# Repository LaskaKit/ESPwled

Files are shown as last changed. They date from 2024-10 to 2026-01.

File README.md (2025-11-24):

# LaskaKit ESPwled

Are you looking for a board that is compatible with the WLED project, which makes it easy to control a variety of LED strips without programming? Then look no further.
Simply upload the WLED program into Laskakit ESPwled from [web browser](https://kno.wled.ge/).

First you connect the board via USB-C cable and then the ESP32-C3, on which the board is based, into recording mode. You do this by pressing and holding the FLASH button, pressing and releasing the RESET button, and then releasing the FLASH button as well. 
You then select the connected Laskakit ESPwled board in the browser and load the program. You will connect to the AP (Wi-Fi access point) that ESPwled created, via, for example, your phone, and fill in your Wi-Fi name and password. Then ESPwled already connects to your wifi and you control the connected LED strips via your browser on your phone, computer or tablet.

The GPIO data pin that is used to control the LED strips is 5, not pin 2 as it is in the default WLED settings -> so it is in the WLED settings to change this pin via the web browser. 
If the LED strip also has a CLK signal, this is connected to GPIO 4.

MicroESPink is equipped with our[universal I2C uŠup port connector](https://blog.laskakit.cz/predstavujeme-univerzalni-konektor-pro-propojeni-modulu-a-cidel-%CE%BCsup/) to which you can connect various sensors - [SHT40 (temperature, humidity)](https://www.laskakit.cz/laskakit-sht40-senzor-teploty-a-vlhkosti-vzduchu/), [BME280 (pressure, temperature, humidity)](https://www.laskakit.cz/arduino-senzor-tlaku--teploty-a-vlhkosti-bme280/), [SCD41 (CO2, temperature, humidity)](https://www.laskakit.cz/laskakit-scd41-senzor-co2--teploty-a-vlhkosti-vzduchu/), [BH1750 (lighting)](https://www.laskakit.cz/laskakit-bh1750-snimac-intenzity-osvetleni/), [APDS-9960 (gesture sensor)](https://www.laskakit.cz/laskakit-apds-9960-senzor-priblizeni-a-gest/) and many other sensors. </br>
Our I2C ushup connector is compatible with Adafruit Stemma and Qwiik from Sparkfun.</br>

The I2C bus is connected as follows, SDA GPIO10, SCL GPIO8. Before initializing the I2C module, it is necessary to add a definition of which pins are on which: wire.begin(10, 8); // (SDA,SCL)

In addition to the I2C uŠup connector, the board has an SPI uŠup connector to which you can connect other SPI peripherals. 

ESPwled has an addressable LED connected to GPIO 9. To control this LED we have a predefined [our example code on ESPwled github](https://github.com/LaskaKit/ESPwled/tree/main/SW).

You may need additional ones: The board comes without LED connector, the pitch is 2.54mm. You can buy [1pc 4pin JST-XH rigth angle](https://www.laskakit.cz/jst-xh-2-54mm-konektor-do-dps--pravouhly/?variantId=5393) or [2pc 2 pin screw terminal block for KF128-2.54 PCB](https://www.laskakit.cz/sroubovaci-svorkovnice-do-dps-kf128-2-54/?variantId=8871) or pin rail. Suitable pigtail with IPEX3 connector for IPEX versions - [Pigtail MHF3/IPEX3 - SMA Female](https://www.laskakit.cz/pigtail-mhf3-ipex3-sma-female--kabel-1-15mm--15cm/), 1.15mm cable, 15cm

Default WLED firmware does not support microphone input for ESP32-C3 (ESPwled), if the microphone input is needed it is necessary to compile WLED firmware with different setting. 

ESPwled connection you may check on the picture below
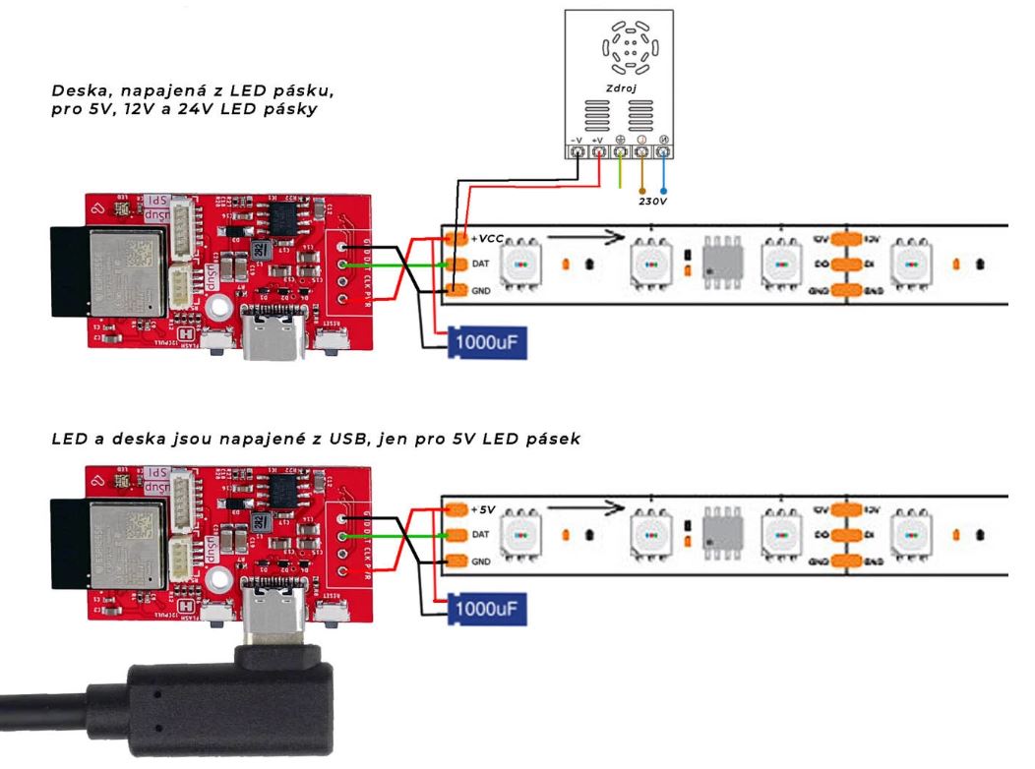
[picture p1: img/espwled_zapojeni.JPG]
ESPwled zapojení LED pásku


The 5V LED strip can thus be powered from the USB-C that is on the board. The 5V, 12 and up to 24V strips then need an external power supply from which the ESPwled can also be powered. 

## ESPwled board is available on https://www.laskakit.cz/laskakit-espwled/?variantId=16928

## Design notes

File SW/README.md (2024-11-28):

### LaskaKit ESPwled is optimalised for WLED software: https://kno.wled.ge
Installation: https://kno.wled.ge/basics/install-binary/
#### Install using web browser: simply installation, just press install https://install.wled.me/ 

#### Install using Platformio https://kno.wled.ge/advanced/compiling-wled/
* Uncomment  default_envs = esp32c3dev in platformio.ini

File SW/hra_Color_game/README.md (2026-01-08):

# ESPWLED Color Game

Webová arkádová hra pro **ESPWLED s ESP32-C3** a **WS2812B LED pásek**, ovládaná přes webový prohlížeč.
Herní logika běží přímo na ESP32-C3, bez cloudu a bez externích služeb.

LED pásek slouží jako herní pole, po kterém se pohybují barevné střely hráče a nepřítele.
Hráč reaguje výběrem správné barvy pomocí webového rozhraní.

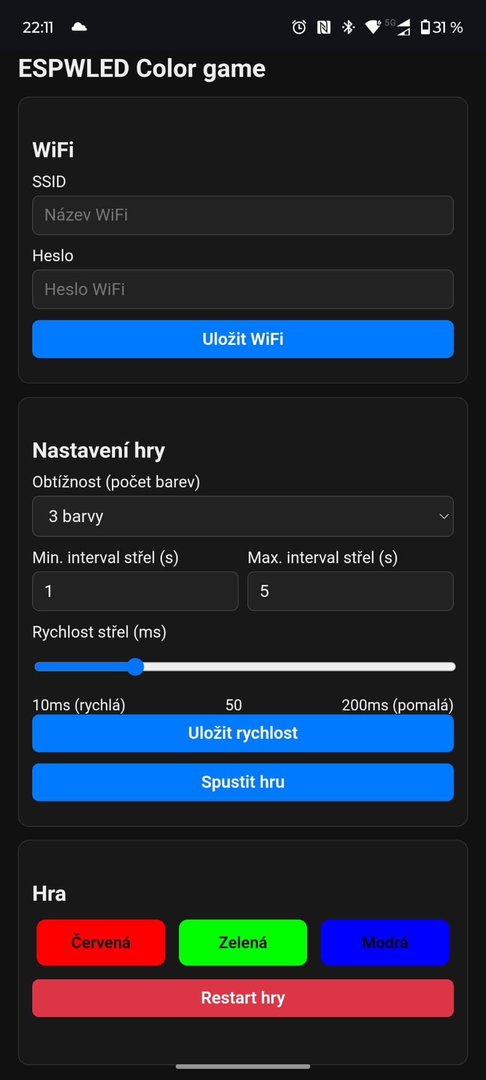
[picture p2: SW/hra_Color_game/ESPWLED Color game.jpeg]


---

## Hlavní vlastnosti

- Arkádová hra běžící přímo na ESPWLED
- Ovládání přes webové rozhraní (PC / mobil)
- LED pásek WS2812B jako herní plocha
- Wi-Fi Access Point + volitelný STA režim
- Ukládání nastavení do NVM (Preferences)
- Nastavitelná obtížnost (počet barev)
- Nastavitelný interval nepřátelské střelby
- Nastavitelná rychlost pohybu střel (10–200 ms)
- Barevné kolize a vizuální exploze
- Offline provoz, žádný cloud

---

## Použitý hardware

- ESPWLED s ESP32-C3 (https://www.laskakit.cz/laskakit-espwled/?variantId=16928)
- WS2812B LED pásek (například https://www.laskakit.cz/led-pasek-neopixel-ws2812b-60led-m-ip30-5m-bily/
- Počet LED: 120 (pro pásek 60 LED/m je potřebná délka 2m)
- Datový pin LED: GPIO 5 (označený na desce jako DAT)

---

## Zapojení LED pásku

| WS2812B | ESPWLED |
|---|---|
| DIN | GPIO 5 (DAT) |
| +5V | 5V (PWR) |
| GND | GND |

Doporučení:
- použijte samostatný 5V zdroj pro LED pásek nebo jej napájejte ESPWLED z USB-C
- nezapomeňte na společnou zem (GND)

---

## Wi-Fi režimy

### Access Point (AP)

ESP32 vždy spustí vlastní Wi-Fi síť:

- SSID: `ESPWLED-Color game`
- Heslo: `espwledgame`
- IP adresa: `192.168.4.1` (typicky)

### Station (STA)

- Připojení k existující Wi-Fi
- Nastavuje se přes webové rozhraní
- Údaje se ukládají do NVM
- Po restartu se ESP automaticky připojí

- SSID a IP adresou jsou zobrazeny v Serial Monitor

---

## Webové rozhraní

Po připojení k ESP otevřete IP adresu v prohlížeči.

### Funkce webu

#### Wi-Fi
- Zadání SSID a hesla
- Uložení do NVM

#### Nastavení hry
- Obtížnost (3 / 4 / 6 / 8 barev)
- Minimální interval střel nepřítele (s)
- Maximální interval střel nepřítele (s)
- Rychlost pohybu střel (10–200 ms)

#### Ovládání hry
- Spuštění hry
- Barevná tlačítka pro střelbu
- Restart hry

---

## Herní princip

- Hráčova základna je na začátku LED pásku
- Nepřítel je na konci LED pásku
- Obě strany vystřelují barevné střely
- Střely se pohybují po LED pásku
- Pokud se střely stejné barvy setkají → exploze
- Pokud nepřátelská střela dosáhne hráčovy základny → konec hry
- Skóre se zvyšuje za každý úspěšný zásah

---

## Ukládaná nastavení (Preferences)

Do NVM se ukládá:

- STA Wi-Fi SSID
- STA Wi-Fi heslo
- Rychlost pohybu střel (shotSpeedMs)

Po restartu zařízení se tato nastavení automaticky načtou.

---

## Použité knihovny

- WiFi
- Preferences
- Adafruit NeoPixel
- ESPAsyncWebServer
- AsyncTCP

---

## Poznámky k výkonu

- Pohyb střel je řízen pomocí `millis()`
- Rychlost střel je globální pro hráče i nepřítele
- LED rendering probíhá v každé iteraci `loop()`
- Exploze jsou časově řízené s plynulým zhasínáním

---

## Licence

Creative Commons BY-NC 4.0

---

Laskakit (2026)

ESPWLED - https://www.laskakit.cz/laskakit-espwled/?variantId=16928

LED pásek - https://www.laskakit.cz/led-pasek-neopixel-ws2812b-60led-m-ip30-5m-bily

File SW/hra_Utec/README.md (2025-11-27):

# Uteč! – ESPWLED hra s adresovatelným LED páskem





**Uteč!** je interaktivní hra pro [ESPWLED (ESP32-C3)](https://www.laskakit.cz/laskakit-espwled/?variantId=16925), kde hráč závodí s duchem po LED polích. Cílem je dosáhnout koncového pole dříve než duch. Hráč postupuje odpovídáním na otázky, duch postupuje při chybné odpovědi.

---
 
  ## Hardware

| Komponenta | Specifikace | Odkaz |
|---|---|---|
| ESPWLED | ESP32-C3 + LED driver | [laskakit.cz](https://www.laskakit.cz/laskakit-espwled/?variantId=16925) |
| LED pásek | WS2812B, 120 LED (2m/60LED/m) | [laskakit.cz WS2812B](https://www.laskakit.cz/vyhledavani/?string=ws2812b) [LaskaKit ESPwled adaptér pro LED pásek JST-SM-3](https://www.laskakit.cz/laskakit-espwled-adapter-pro-led-pasek-jst-sm-3--10-cm/), [4pinový konektor pro LED pásek](https://www.laskakit.cz/jst-xh-2-54mm-konektor-do-dps--pravouhly/?variantId=5393) |
| Napájení | 5V/2A+ | [USB adapter](https://www.laskakit.cz/sitovy-napajeci-adapter-5v-3a--kabel-usb-c-usb-a-vypinac) | 

- Počet LED: 120 (8 LED na pole), pásek ve verzi 60LED/m zkraťte na 2m
- LED pásek i ESPWLED se bude napájet z nabíječky s USB-C konektorem. Nabíjecí adaptér musí být minimálně 5V/3A

**Propojení:**  
`LED_DATA → DAT(GPIO5)`  
`LED_GND → GND`  
`LED_5V → PWR(5V)`

---

## Software & Knihovny

- **Arduino framework pro ESP32-C3**
- **Knihovny:**
  - [Adafruit_NeoPixel](https://github.com/adafruit/Adafruit_NeoPixel) – ovládání LED pásu
  - [AsyncTCP](https://github.com/me-no-dev/AsyncTCP) – asynchronní TCP
  - [ESPAsyncWebServer](https://github.com/me-no-dev/ESPAsyncWebServer) – web server
  - Preferences – ukládání Wi-Fi přihlašovacích údajů

---

## Princip hry

1. Hráč začíná na poli 3, duch na poli 1.
2. Správná odpověď → hráč postupuje o 1 pole.
3. Špatná odpověď → duch postupuje o 1–3 pole podle kola.
4. Možnost **"Ještě jednou"** max 2x, pro přeskočení otázky bez pohybu ducha.
5. LED pás zobrazuje:
   - Zelené LED = hráč
   - Červené LED = duch
   - Ostatní pole = dimované LED
6. Konec hry:
   - Hráč dosáhne posledního pole → výhra hráče
   - Duch dohoní hráče → výhra ducha

---

## Formát otázek

Otázky se nahrávají přes webové rozhraní v tomto formátu (7 polí, oddělených středníkem):
	`ID;Otázka;Odpověď1;Odpověď2;Odpověď3;Odpověď4;IndexSprávnéOdpovědi(1..4)`

### Prompt pro generování otázek a odpovědí
Jsi AI generátor kvízových otázek. Vytvoř prosím otázky ve formátu vhodném pro hru **"Uteč!"** na ESP32-C3.</br>
Otázky musí být zaměřeny na (**zde zadejte téma otázek**). </br>
*Např. Matematiku Základní školy pro první stupeň, Fyziku pro střední školu, Všeobecné znalosti o Evropské Unii a jiné*</br>
Každá otázka musí mít přesně 7 částí oddělených středníkem (`;`):</br>

ID otázky;Otázka;Odpověď1;Odpověď2;Odpověď3;Odpověď4;Index Správné odpovědi (od 1 do 4)

Pravidla

1. **ID** musí být číslo větší než 0, unikátní pro každou otázku.  
2. **Otázka** musí být jasná, krátká a srozumitelná.  
3. Každá otázka musí mít **4 možné odpovědi**.  
4. **Správná odpověď** je číslo od 1 do 4 podle pořadí odpovědí.  
5. **Nepoužívej čárky** mezi odpověďmi, protože pole se oddělují středníkem.  
6. Vytvoř **30 otázek** v tomto formátu.  
7. Výstup má být **čistě textový**, každá otázka na novém řádku, bez úvodních komentářů.

Příklad</br>
1;Kolik je 2+2?;3;4;5;6;2</br>
2;Hlavní město Francie?;Paříž;Londýn;Berlín;Řím;1

---

## Instalace

1. Nainstalujte Arduino IDE s podporou ESP32-C3.
2. Nainstalujte knihovny:
   - Adafruit_NeoPixel
   - AsyncTCP
   - ESPAsyncWebServer
3. Povolte USB CDC On Boot (menu - Tools - nastavit na Enabled)
4. Nahrajte `hra_Utec.ino` do ESPWLED.
   - Pokud nelze program do ESPWLED nahrát, přepněte jej manuálně do bootloader módu.
   - Připojte nabíjecí adaptér do USB-C konektoru.
   - Stiskněte a držte tlačítko FLASH
   - Stiskněte a uvolněte tlačítko RESET
   - Uvolněte tlačítko RESET
   - Nahrajte program do ESPWLED
5. Po spuštění:
   - ESPWLED (ESP32-C3) vytvoří Wi-Fi Access Point `hraUtecAP` (heslo `utec1234`).
   - Připojte se přes prohlížeč na `http://192.168.4.1`.
   - Nahrajte otázky a spusťte hru.

> Pokud uložíte Wi-Fi přihlašovací údaje, ESP32-C3 (ESPWLED) se automaticky pokusí připojit k domácí síti a AP zůstane aktivní jako fallback.

---

## Webové rozhraní

- Zobrazení aktuální otázky a odpovědí
- Odeslání odpovědi
- Přeskočení otázky (`Ještě jednou`)
- Restart hry
- Nahrání nových otázek
- Nastavení Wi-Fi

LED pás zobrazuje dynamicky pozice hráče a ducha.

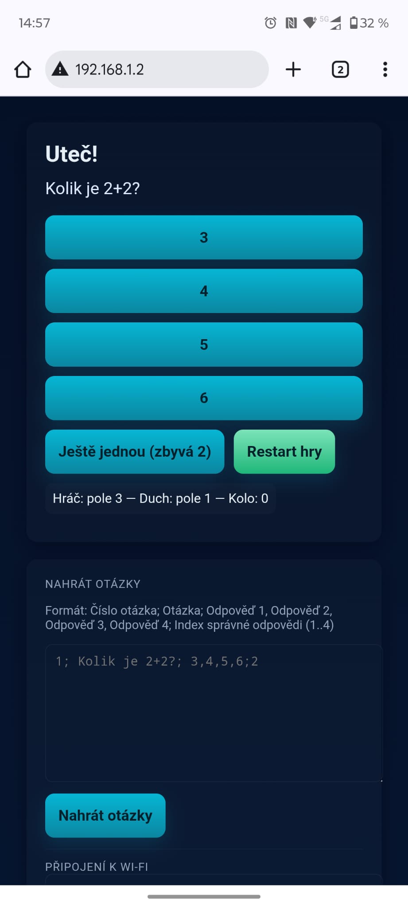
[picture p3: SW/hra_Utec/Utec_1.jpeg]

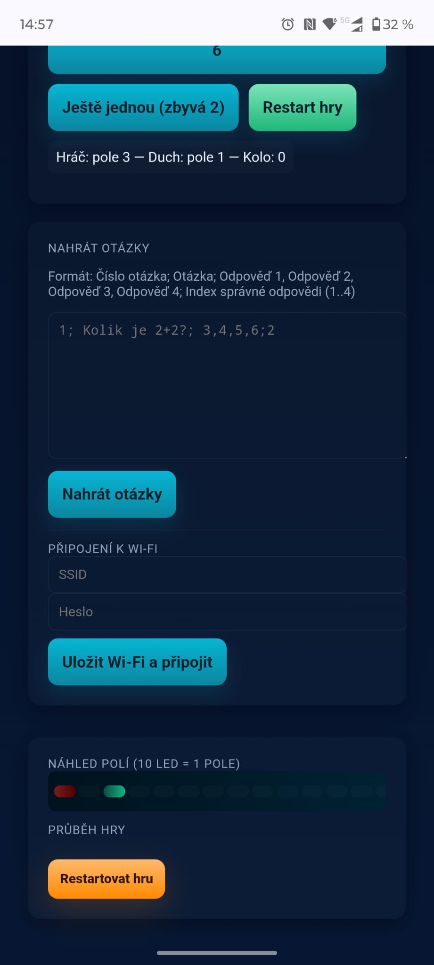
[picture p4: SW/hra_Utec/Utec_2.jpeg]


---

## Ukázka LED zobrazení

- Zelené = hráč  
- Červené = duch  
- Modré (dimované) = pole

---

### ESPWLED, LED pásek i USB adaptér koupíte na [laskakit.cz](https://www.laskakit.cz/laskakit-espwled/?variantId=16925)
---

## Licence

Projekt je open-source a můžete jej používat a upravovat podle potřeby. 

laskakit.cz 2025

---

*Vytvořeno pro zábavu a vzdělávací účely – hra kombinuje ESPWLED, NeoPixel a webové rozhraní.*

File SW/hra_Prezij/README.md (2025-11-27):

# hra Přežij! ESPWLED hra s adresovatelným LED páskem





## Popis projektu

**Interaktivní kvízová hra "Přežij!"** pro ESP32-C3 (ESPWLED), kde hráč odpovídá na otázky a snaží se zničit nepřítele střelami vystřelenými díky správným odpovědím. Nepřítel střílí zpět každé **4 sekundy** a hráč musí být rychlejší!

### Jak hrát

- **Správná odpověď**: vystřelí protistřelu (z LED 0 → LED 119) 🟢  
- **Špatná odpověď**: žádná střela ❌  
- **Kolize střel**: exploze, zbylé střely pokračují 💥  
- **Výhra**: hráčova střela dosáhne nepřítele (LED 119) 🎉  
- **Prohra**: nepřátelova střela dosáhne hráče (LED 0) 💀  

## Požadavky

### Hardware

| Komponenta | Specifikace | Odkaz |
|---|---|---|
| ESPWLED | ESP32-C3 + LED driver | [laskakit.cz](https://www.laskakit.cz/laskakit-espwled/?variantId=16925) |
| LED pásek | WS2812B, 120 LED (2m/60LED/m) | [laskakit.cz WS2812B](https://www.laskakit.cz/vyhledavani/?string=ws2812b) |
| Napájení | 5V/2A+ | [USB adapter](https://www.laskakit.cz/sitovy-napajeci-adapter-5v-3a--kabel-usb-c-usb-a-vypinac) | 

LED pásek i ESPWLED se bude napájet z nabíječky s USB-C konektorem. Nabíjecí adaptér musí být minimálně 5V/3A
LED pásek ve verzi 60LED/m zkraťte na 2m

**Propojení:**  
`LED_DATA → DAT(GPIO5)`  
`LED_GND → GND`  
`LED_5V → PWR(5V)`

## Vlastnosti

- Webové UI přes WiFi AP (SSID: hraPrezijAP, heslo: prezij1234)  
- Otázky se nahrávají přes webové rozhraní v tomto formátu (7 polí, oddělených středníkem):
	`ID;Otázka;Odpověď1;Odpověď2;Odpověď3;Odpověď4;IndexSprávnéOdpovědi(1..4)`
- Uložení WiFi přihlašovacích údajů (automatické připojení)  
- 2x "Ještě jednou" (skip otázky)  
- Real-time animace střel a exploze (50ms krok)  
- Otázky uložené v RAM (max 200 otázek)

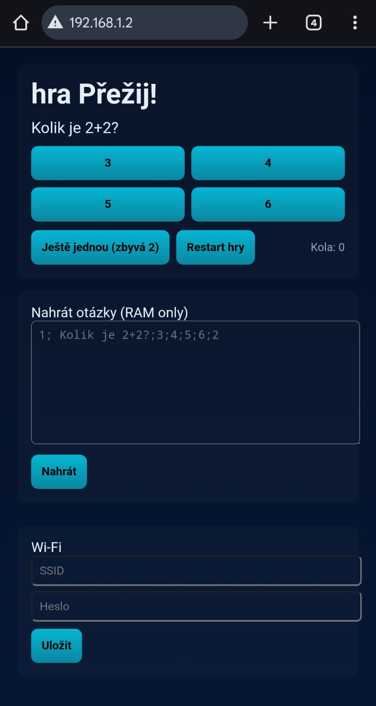
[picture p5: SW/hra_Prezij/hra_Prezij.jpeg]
Webová stránka hry
  

### Prompt pro generování otázek a odpovědí
Jsi AI generátor kvízových otázek. Vytvoř prosím otázky ve formátu vhodném pro hru **"Uteč!"** na ESP32-C3.</br>
Otázky musí být zaměřeny na (**zde zadejte téma otázek**). </br>
*Např. Matematiku Základní školy pro první stupeň, Fyziku pro střední školu, Všeobecné znalosti o Evropské Unii a jiné*</br>
Každá otázka musí mít přesně 7 částí oddělených středníkem (`;`):</br>

ID otázky;Otázka;Odpověď1;Odpověď2;Odpověď3;Odpověď4;Index Správné odpovědi (od 1 do 4)

Pravidla

1. **ID** musí být číslo větší než 0, unikátní pro každou otázku.  
2. **Otázka** musí být jasná, krátká a srozumitelná.  
3. Každá otázka musí mít **4 možné odpovědi**.  
4. **Správná odpověď** je číslo od 1 do 4 podle pořadí odpovědí.  
5. **Nepoužívej čárky** mezi odpověďmi, protože pole se oddělují středníkem.  
6. Vytvoř **30 otázek** v tomto formátu.  
7. Výstup má být **čistě textový**, každá otázka na novém řádku, bez úvodních komentářů.

Příklad</br>
1;Kolik je 2+2?;3;4;5;6;2</br>
2;Hlavní město Francie?;Paříž;Londýn;Berlín;Řím;1

## Instalace

1. Nainstalujte Arduino IDE s podporou ESP32-C3.
2. Nainstalujte knihovny:
   - Adafruit_NeoPixel
   - AsyncTCP
   - ESPAsyncWebServer
3. Povolte USB CDC On Boot (menu - Tools - nastavit na Enabled)
4. Nahrajte `hra_Prezij.ino` do ESPWLED.
   - Pokud nelze program do ESPWLED nahrát, přepněte jej manuálně do bootloader módu.
   - Připojte nabíjecí adaptér do USB-C konektoru.
   - Stiskněte a držte tlačítko FLASH
   - Stiskněte a uvolněte tlačítko RESET
   - Uvolněte tlačítko RESET
   - Nahrajte program do ESPWLED
5. Po spuštění:
   - ESPWLED (ESP32-C3) vytvoří Wi-Fi Access Point `hraPrezijAP` (heslo `prezij1234`).
   - Připojte se přes prohlížeč na `http://192.168.4.1`.
   - Nahrajte otázky a spusťte hru.

> Pokud uložíte Wi-Fi přihlašovací údaje, ESP32-C3 (ESPWLED) se automaticky pokusí připojit k domácí síti a AP zůstane aktivní jako fallback. Není pak nutné se připojovat telefonem k WiFI hraPrezijAP, ale zůstat v domácí síti

## Ukázka LED zobrazení

- Zelené = střela hráče  
- Červené = střela protivníka  
- Modré (dimované) = pole

---

### ESPWLED, LED pásek i USB adaptér koupíte na [laskakit.cz](https://www.laskakit.cz/laskakit-espwled/?variantId=16925)
---

## Licence

Projekt je open-source a můžete jej používat a upravovat podle potřeby. 

laskakit.cz 2025

---

*Vytvořeno pro zábavu a vzdělávací účely – hra kombinuje ESPWLED, NeoPixel a webové rozhraní.*

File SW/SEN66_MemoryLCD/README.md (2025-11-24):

# SEN66 + ESPwled (ESP32-C3) + MemoryLCD + RGB LED

**Autor:** [laskakit.cz](https://www.laskakit.cz) (2025)

## Popis
Projekt pro čtení hodnot ze senzoru **Sensirion SEN66** (CO₂, teplota, vlhkost, VOC, NOx, PM2.5)  
a jejich zobrazení na **Sharp Memory LCD** (400x240).  

Hodnoty se vykreslují dynamicky – před každým překreslením se smaže oblast podle **bounding boxu** staré i nové hodnoty,  
aby nezůstávaly zbytky při změně délky čísla (např. `99 → 100`).  

**RGB LED** signalizuje kvalitu vzduchu podle koncentrace CO₂.

---

## Nutné knihovny
- [Adafruit_GFX](https://github.com/adafruit/Adafruit-GFX-Library)  
- [Adafruit_SharpMem](https://github.com/adafruit/Adafruit_SHARP_Memory_Display)  
- [Adafruit_NeoPixel](https://github.com/adafruit/Adafruit_NeoPixel)  
- [SensirionI2cSen66](https://github.com/Sensirion/arduino-i2c-sen66)  

---

## Hardware
- [ESPwled (ESP32-C3)](https://www.laskakit.cz/laskakit-espwled/)  
- [SEN66 (I2C)](https://www.laskakit.cz/senserion-sen66-sin-t-senzor-kvality-ovzdusi/)  
- [Propojovací kabel I2C uŠup](https://www.laskakit.cz/laskakit-airboard-propojovaci-kabel-pro-senserion-sen6x-senzor-kvality-ovzdusi/)  
- [Sharp Memory LCD 400x240 (SPI)](https://www.laskakit.cz/laskakit-2-7--400x240-lcd-memory-displej/)  
- [Propojovací kabel SPI uŠup](https://www.laskakit.cz/--sup-spi-jst-sh-6-pin-kabel-10cm/)  

---

## Ukázka výstupu
- Na LCD se zobrazuje:  
  - CO₂ (ppm)  
  - Teplota (°C)  
  - Relativní vlhkost (%)  
  - VOC index  
  - NOx index  
  - PM2.5 (µg/m³)  

- RGB LED svítí:  
  - 🟢 zeleně při CO₂ < 800 ppm  
  - 🟡 žlutě při 800–1400 ppm  
  - 🔴 červeně při CO₂ > 1400 ppm  
  - 🔵 modře při chybě senzoru

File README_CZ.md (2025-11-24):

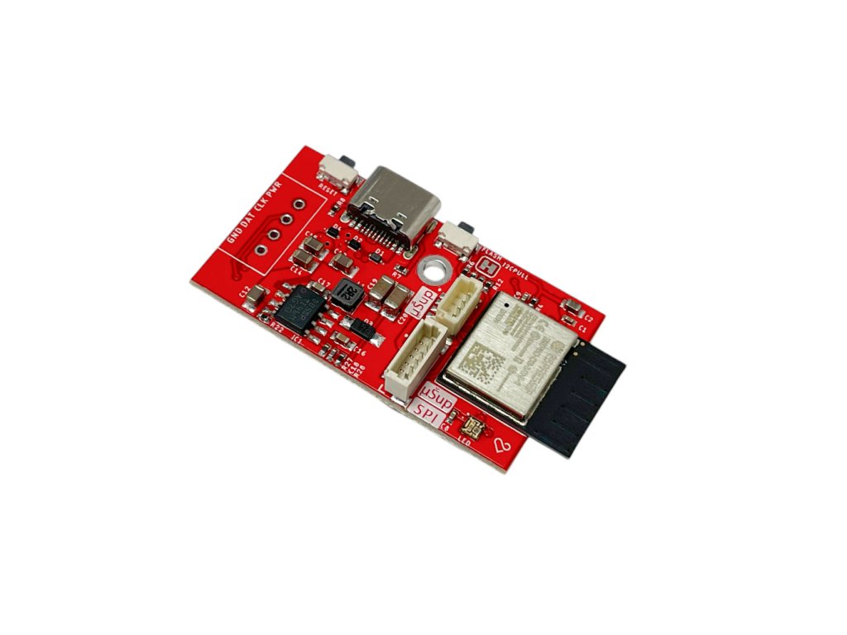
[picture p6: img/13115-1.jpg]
ESPwled

# LaskaKit ESPwled

Hledáš desku, která je kompatibilní s projektem WLED, který přináší naprosto jednoduché ovládání nejrůznějších LED pásků bez nutnosti programování? Pak už dál hledat nemusíš.
Program WLED do Laskakit ESPwled nahraješ jednoduše z [webového prohlížeče projektu](https://kno.wled.ge/).

Nejprve připojíš desku skrze USB-C kabel a pak ESP32-C3, na kterém je deska založena, do nahrávacího režimu. To provedeš tak, že zmáčkneš a držíš tlačítko FLASH, zmáčkneš a uvolníš tlačítko RESET a poté uvolníš i tlačítko FLASH. 
Poté v prohlížeči vybereš připojenou Laskakit ESPwled desku a nahraješ program. Připojíš se na AP (Wi-Fi access point), kterou ESPwled vytvořil, přes třeba tvůj telefon a vyplníš jméno a heslo tvé Wi-Fi. Poté se ESPwled už připojí do tvé wifi a přes tvůj prohlížeč v telefonu, počítači nebo tabletu ovládáš připojené LED pásky.

DAtový GPIO pin, který se používá na ovládání LED pásků je 5, ne pin 2 jak je ve výchozím nastavení WLED -> je tedy v nastavení WLED tento pin změnit skrze webový prohlížeč. 
Pokud má LED pásek i CLK signál, ten je připojen na GPIO 4.

Deska samotná obsahuje navíc [náš univerzální I2C uŠup konektor](https://blog.laskakit.cz/predstavujeme-univerzalni-konektor-pro-propojeni-modulu-a-cidel-%CE%BCsup/) ke kterým můžeš připojit nejrůznější čidla - [SHT40 (teplota, vlhkost)](https://www.laskakit.cz/laskakit-sht40-senzor-teploty-a-vlhkosti-vzduchu/), [BME280 (tlak, teplota, vlhkost)](https://www.laskakit.cz/arduino-senzor-tlaku--teploty-a-vlhkosti-bme280/), [SCD41 (CO2, teplota, vlhkost)](https://www.laskakit.cz/laskakit-scd41-senzor-co2--teploty-a-vlhkosti-vzduchu/), [BH1750 (osvětlení)](https://www.laskakit.cz/laskakit-bh1750-snimac-intenzity-osvetleni/), [APDS-9960 (senzor gest)](https://www.laskakit.cz/laskakit-apds-9960-senzor-priblizeni-a-gest/) a spoustu další senzorů. </br>
Náš I2C uŠup konektor je kompatibilní s Adafruit Stemma a Qwiik od Sparkfun.</br>
I2C sběrnice je připojeno takto, SDA GPIO10, SCL GPIO8. Je potřeba před iniciací i2c modulu přidat definici na kterých PINech jsou: Wire.begin(10, 8); // (SDA,SCL)

Kromě I2C uŠup konektoru má deska i SPI uŠup konektor, ke kterému můžeš připojit další SPI periférie. 

ESPwled má osazenou adresovatelnou LED připojenou na GPIO 9. Pro ovládání této LED máme předpřiravený [vlastní vzorový kód na našem github](https://github.com/LaskaKit/ESPwled/tree/main/SW).

Dodatečné možna budeš potřebovat:
Deska je dodávána bez LED konektoru, rozteč je 2.54mm. Můžeš dokoupit 1ks [4pin JST-XH pravoúhlý](https://www.laskakit.cz/jst-xh-2-54mm-konektor-do-dps--pravouhly/?variantId=5393) nebo [2ks 2 pin šroubovací svorkovnice do DPS KF128-2.54](https://www.laskakit.cz/sroubovaci-svorkovnice-do-dps-kf128-2-54/?variantId=8871) anebo kolíkovou lištu.
Vhodný pigtail s konektorem IPEX3 pro verze IPEX - [Pigtail MHF3/IPEX3 - SMA Female](https://www.laskakit.cz/pigtail-mhf3-ipex3-sma-female--kabel-1-15mm--15cm/), kabel 1,15mm, 15cm

Výchozí WLED firmware nepodporuje vstup z mikrofonu pro ESP32-C3 (ESPwled), pokud je mikrofonní vstup potřeba, je nutné si zkompilovat WLED firmware s jiným nastavením.

Zapojení LED pásku vidíš na obrázku níže
ESPwled zapojení LED pásku

5V LED pásek tak může být napájen z USB-C, který je na desce. Pásky 5V, 12 a až 24V pak potřebují externí zdroj ze kterého se také může ESPwled napájet. 

## ESPwled je k dostání na https://www.laskakit.cz/laskakit-espwled/?variantId=16928

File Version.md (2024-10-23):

#### Version 1.1
- LED IO chnged from 21 to 9
- FSPI_CS IO changed to 3
### Version 1.0
- Initial | Počáteční

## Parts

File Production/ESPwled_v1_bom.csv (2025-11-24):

Comment | Designator | Footprint | LCSC Part #
2.2uH | L1 | L3X3 | C167747
4.7k | R12 | R0402
5.1k | R7 R8 | R0402
8.2n | C16 | C0603
10k | R4 R5 R6 R17 | R0402
12k | R27 | R0402
20k | R22 | R0402
22uF | C2 | C0603
22uF/35V | C12 C13 C14 C15 | C0805
68k | R28 | R0402
100n | C9 | C0402
100n | C17 | C0603
100nF | C1 C8 | C0402
100uF | C19 C20 | C1206
330p | C18 | C0402
ESP32-C3-MINI-1-N4 | IC2 | ESP32C3MINI1N4
LESD5D5.0CT1G | D1 D2 D4 | LESD5D50CT1G
LMR14050DDAR | IC1 | SO08-EPAD | C155484
CRS08 | D3 | SOD123-F | C141550
SK6812-EC20 | LED | SK6812EC20
TS-1086E-AC03526 | FLASH RESET | 1TS003B16003500A | C720473
USB-C_2-16PIN | J1 | USBC_USB-C-16P-5 | C2837092
USUP_4P_V | J3 | 1X04_1MM_RA_VERT | C371588
USUP_SPI_CONNECTOR_VERT | J2 | 1X06_1MM_RA_VERT | C145963
22uF | C3 C4 | C0603
47k | R1 R18 | R0402
62R | R9 R10 | R0402
100nF | C5 | C0402
DMG2305UX | Q5 | MICRO3 | C144153
ME6211C33M5G | IC4 | SOT23-5
MMDT5401 | Q3 | SC70-6 | C54540
SN74AHCT125PW | U1 | SOP65P640X120-14N | C36365
JST-XH-4P/90 | P5 | JST-XH-4P/90 | C7429643

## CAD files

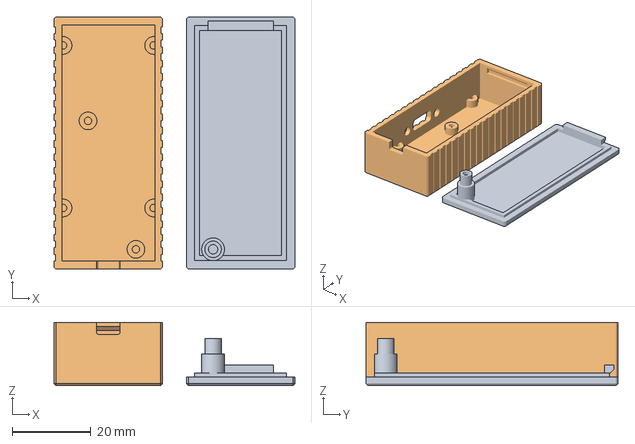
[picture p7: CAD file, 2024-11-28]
3D/slimcase.3mf
61.2 x 64.0 x 16.0 mm
Bottom_cover v10
Top_cover v27

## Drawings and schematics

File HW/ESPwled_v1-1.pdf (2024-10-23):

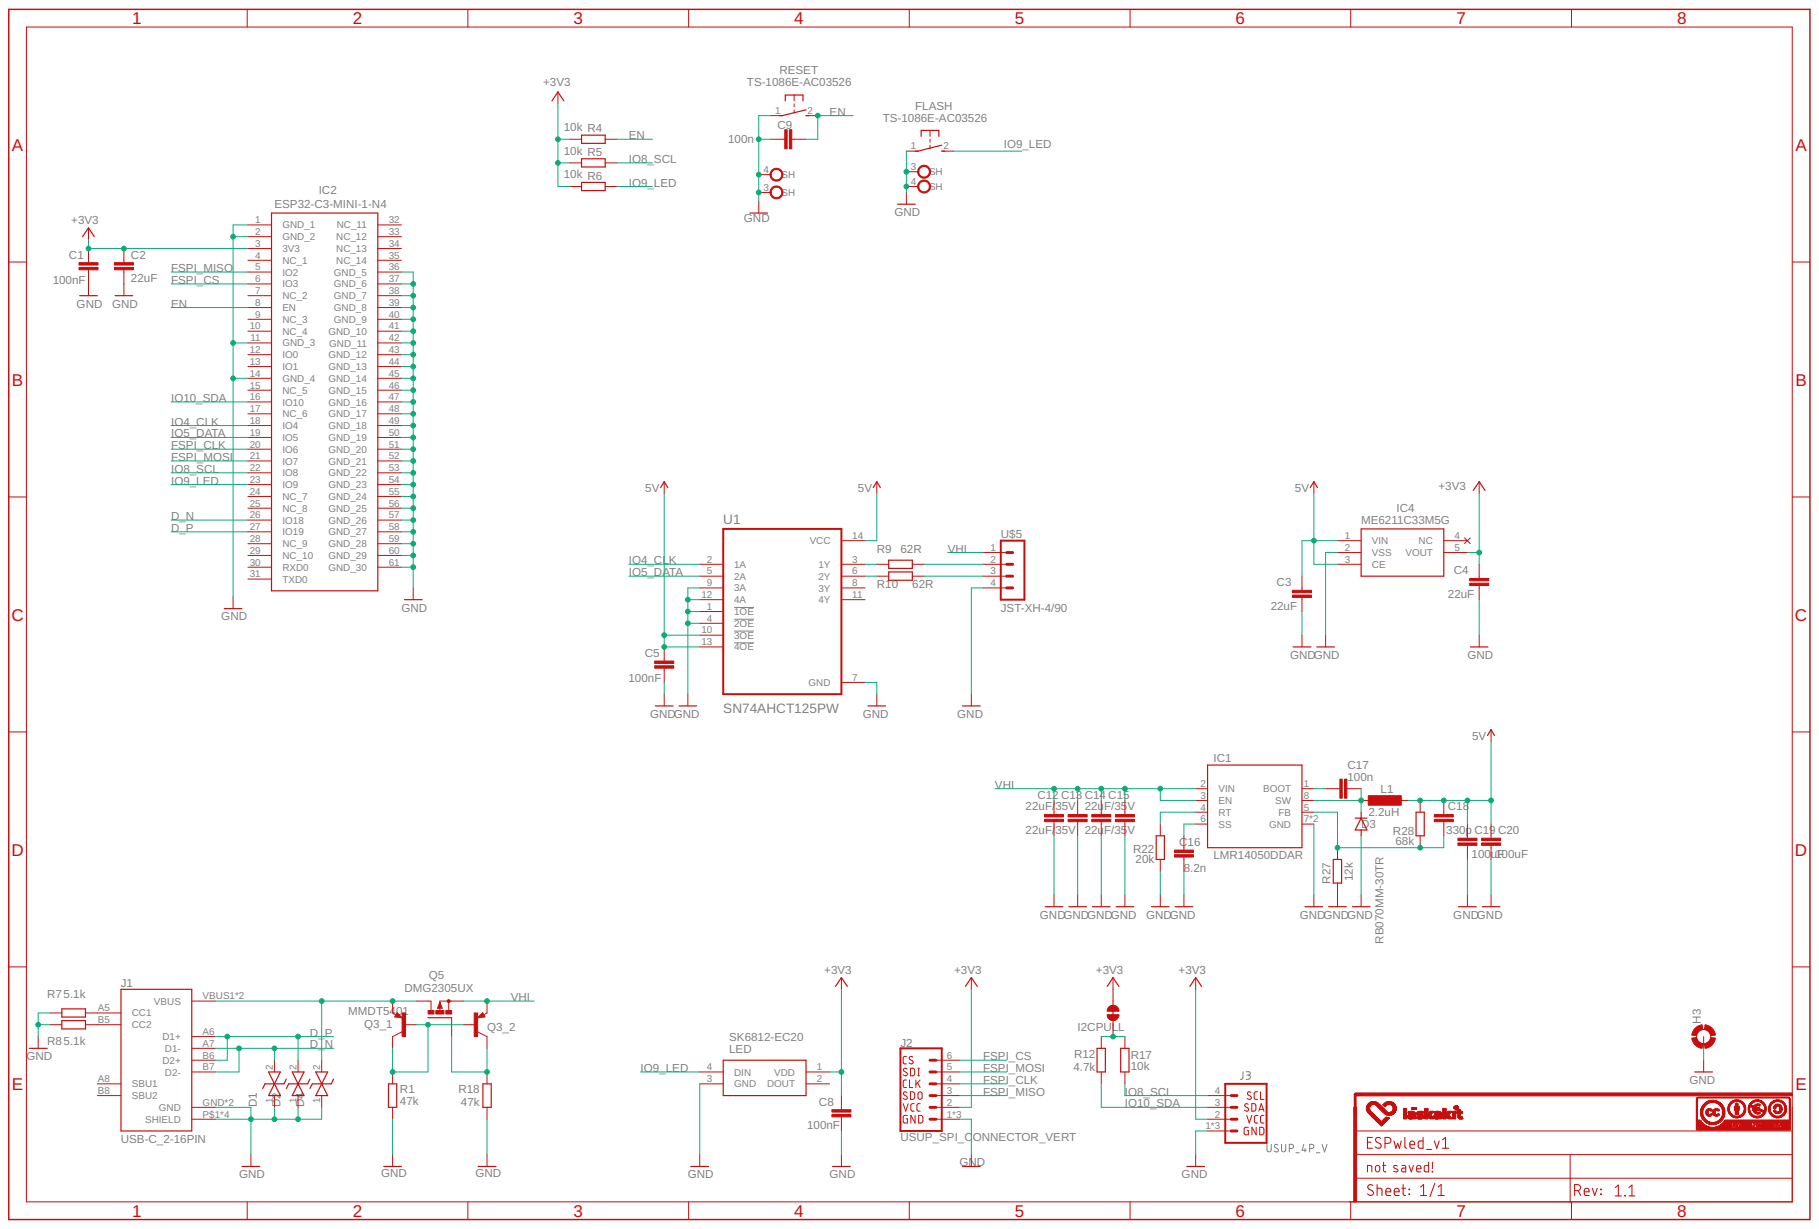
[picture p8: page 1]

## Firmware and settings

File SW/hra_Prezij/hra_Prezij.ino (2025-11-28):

/*
================================================================================
hra Přežij
================================================================================

POPIS PROJEKTU:
Tento projekt vytváří interaktivní kvízovou hru "Přežij!" kde hráč odpovídá na otázky
a snaží se zničit nepřítele střelami vystřelenými díky správně zodpovězeným otázkám.
Nepřítel současně střílí zpět a hráč musí odpovídat dost rychle, aby ho vystřelil dříve,
než ho nepřítel zasáhne.

HRÁ: 
- Hráč odpovídá na otázky s 4 možnostmi odpovědí (otázky jsou nahrány skrze web)
- Nepřítel střílí automaticky každé 4 sekundy (z LED 119 → LED 0)
- Správná odpověď = vystřelí protistřelu směrem k nepřítele (z LED 0 → LED 119)
- Špatná odpověď = žádná střela
- Kolize střel = exploze, střely mimo explozi zůstávají aktivní
- Výhra hráče = jeho střela dosáhne nepřítele (LED 119)
- Prohra = střela nepřítele dosáhne hráče (LED 0)

VYŽADOVANÝ HARDWARE:
- ESPWLED (https://www.laskakit.cz/laskakit-espwled/?variantId=16925)
- WS2812B / NeoPixel LED pásek (https://www.laskakit.cz/vyhledavani/?string=ws2812b) (60 LED/m = 2m = 120 LED, řízení GPIO 5)
- Napájení: 5V/2A+ pro LED pásku
- Propojení: LED_DATA → DAT(GPIO5), LED_GND → GND, LED_5V → PWR(5V)

POUŽITÉ KNÍHOVNY:
• Adafruit_NeoPixel (v1.15.2+) - ovládání WS2812B LED pásky
• ESPAsyncWebServer (3.9.1+) - asynchronní webový server
• AsyncTCP (3.4.7+) - TCP základ pro async web server

VLASTNOSTI:
• Webové UI přes WiFi AP (SSID: hraPrezijAP, heslo: prezij1234)
• Nahrát otázky přímo v prohlížeči (formát: "Číslo otázky;Otázka?;Odpivěď1;Odpivěď2;Odpivěď3;Odpivěď4;Index správné odpovědi 1..4")
• Uložení WiFi přihlašovacích údajů (automatické připojení)
• 2x "Ještě jednou" (skip otázky)
• Real-time animace střel a exploze (50ms krok)
• Otázky uloženy v RAM (max 200 otázek)

POKYNY:
1. Nahrát kód do ESPWLED přes Arduino IDE / prezij1234
2. Připojit se na WiFi "hraPrezijAP" (heslo: utec1234)
3. Otevřít IP adresu (obvykle 192.168.4.1)
4. Nahrát otázky a nastavit WiFi (volitelně)
5. Hrát! Odpovídat na otázky dříve než nepřítel vystřelí

AUTOR: laskakit.cz (2025)
VERZE: 1.0 
================================================================================
*/

#include <WiFi.h>
#include <AsyncTCP.h>
#include <ESPAsyncWebServer.h>
#include <Adafruit_NeoPixel.h>
#include <Preferences.h>
#include <vector>

#define LED_PIN        5
#define LED_COUNT      120

Adafruit_NeoPixel strip(LED_COUNT, LED_PIN, NEO_BRG + NEO_KHZ800);
AsyncWebServer server(80);
Preferences prefs;

// ---- Otazky ----
struct Question {
  String id;
  String text;
  String answers[4];
  uint8_t correctIndex; // 1..4
};

#define MAX_QUESTIONS 200
std::vector<Question> questions; // RAM-only

int currentQuestionIndex = 0;
int turnCounter = 0;
int skipsUsed = 0;
bool gameOver = false;
String gameResult = ""; // "hrac zvitezil" / "prothrac zvitezil"

// WiFi AP 
const char* apSsid = "hraPrezijAP";
const char* apPass = "prezij1234";
// ulozeno do trvale pameti
String savedSSID = "";
String savedPass = "";

// citace
int lastValidCount = 0;
int lastInvalidCount = 0;

// ---- Shot system ----
// Protivnika (ESPWLED) strela: jedna střela z LED_COUNT-1 -> 0
int enemyShotPos = -1; // -1 = no active enemy shot
unsigned long lastEnemyShotTime = 0;
const unsigned long ENEMY_SHOT_INTERVAL = 4000UL; // 4s

// Hrac: strely
#define MAX_PLAYER_SHOTS 10
int playerShots[MAX_PLAYER_SHOTS]; // positions
int playerShotCount = 0;

// Casovani pohybu strely
unsigned long lastShotStep = 0;
const unsigned long SHOT_STEP = 50UL; // 50 ms

// Animace exploze
bool explosionActive = false;
int explosionCenter = -1;
int explosionFrame = 0;
const int EXPLOSION_FRAMES = 6;

// UI log (RAM)
String gameLog = "";

// Deklarace
void drawScene();
bool parseQuestionsFromString(const String &data);
String generateIndexHtml();
void nextQuestionRandom();
void resetGameState();
void enemyTryShoot();
void updateShots();
void drawShotsToStrip();
void triggerExplosion(int pos);
void playExplosionFrame();
String jsonEscape(const String &s);

// Utilities
void clearStrip() {
  for (int i=0;i<LED_COUNT;i++) strip.setPixelColor(i, 0);
}
uint32_t colorRGB(uint8_t r, uint8_t g, uint8_t b) { return strip.Color(r,g,b); }

// ---------------- Implementace ----------------

void resetGameState() {
  turnCounter = 0;
  skipsUsed = 0;
  gameOver = false;
  gameResult = "";
  enemyShotPos = -1;
  playerShotCount = 0;
  for (int i=0;i<MAX_PLAYER_SHOTS;i++) playerShots[i] = -1;
  explosionActive = false;
  explosionCenter = -1;
  explosionFrame = 0;
  lastEnemyShotTime = millis();
  addGameLogOnce("Hra restartována.");
  if (questions.size() > 0) currentQuestionIndex = 0;
  drawScene();
}

void nextQuestionRandom() {
  if (questions.size() == 0) return;
  int idx = random(0, questions.size());
  currentQuestionIndex = idx;
}

bool parseQuestionsFromString(const String &data) {
  questions.clear();
  lastValidCount = 0;
  lastInvalidCount = 0;

  int start = 0;
  while (start < (int)data.length()) {
    int eol = data.indexOf('\n', start);
    if (eol == -1) eol = data.length();
    String line = data.substring(start, eol);
    start = eol + 1;
    line.trim();
    if (line.length() == 0) continue;

    // rozdeleni ';'
    std::vector<String> parts;
    int pstart = 0;
    while (pstart <= (int)line.length()) {
      int p = line.indexOf(';', pstart);
      if (p == -1) p = line.length();
      String part = line.substring(pstart, p);
      part.trim();
      parts.push_back(part);
      pstart = p + 1;
      if (p >= (int)line.length()) break;
    }

    if (parts.size() != 7) { lastInvalidCount++; continue; }
    if (parts[0].length() == 0) { lastInvalidCount++; continue; }
    int id = parts[0].toInt();
    if (id <= 0) { lastInvalidCount++; continue; }
    if (parts[1].length() == 0) { lastInvalidCount++; continue; }
    bool emptyAnswer = false;
    for (int i = 2; i <= 5; ++i) if (parts[i].length() == 0) { emptyAnswer = true; break; }
    if (emptyAnswer) { lastInvalidCount++; continue; }
    int correct = parts[6].toInt();
    if (correct < 1 || correct > 4) { lastInvalidCount++; continue; }

    Question q;
    q.id = String(id);
    q.text = parts[1];
    q.answers[0] = parts[2];
    q.answers[1] = parts[3];
    q.answers[2] = parts[4];
    q.answers[3] = parts[5];
    q.correctIndex = (uint8_t)correct;
    questions.push_back(q);
    lastValidCount++;
    if ((int)questions.size() >= MAX_QUESTIONS) break;
  }

  Serial.printf("Otazky nahrany: valid=%d invalid=%d", lastValidCount, lastInvalidCount);
  return lastValidCount > 0;
}

void drawScene() {
  // základní pozadí
  clearStrip();
  for (int i = 0; i < LED_COUNT; i++) strip.setPixelColor(i, colorRGB(6, 8, 18));
  // hráčova základna (LED 0)
  strip.setPixelColor(0, colorRGB(0, 120, 0));
  // nepřátelská základna (poslední LED)
  strip.setPixelColor(LED_COUNT - 1, colorRGB(150, 0, 0));

  // střely vždy kreslíme tak, aby byly viditelné i během exploze
  drawShotsToStrip();

  if (explosionActive) {
    // vykreslí explozní animaci navrch střel
    playExplosionFrame();
    // NERETURN - volání playExplosionFrame() samo volá strip.show()
  } else {
    // normální zobrazení
    strip.show();
  }
}


String lastLogMessage = "";

void addGameLogOnce(const String &msg) {
  // Přidej zprávu jen pokud není shodná s poslední přidanou zprávou
  if (msg != lastLogMessage) {
    gameLog = msg + "\n" + gameLog;
    lastLogMessage = msg;
  }
}

void drawShotsToStrip() {
  // strela protivnika
  if (enemyShotPos >= 0 && enemyShotPos < LED_COUNT) {
    strip.setPixelColor(enemyShotPos, colorRGB(255, 0, 0));
    int behind = enemyShotPos + 1;
    if (behind >= 0 && behind < LED_COUNT) strip.setPixelColor(behind, colorRGB(80, 10, 10));
  }
  // strela hrace
  for (int i=0;i<playerShotCount;i++) {
    int p = playerShots[i];
    if (p >= 0 && p < LED_COUNT) {
      strip.setPixelColor(p, colorRGB(0, 255, 0));
      int behind = p - 1; if (behind >= 0 && behind < LED_COUNT) strip.setPixelColor(behind, colorRGB(20,80,30));
    }
  }
}

void triggerExplosion(int pos) {
  explosionActive = true;
  explosionCenter = pos;
  explosionFrame = 0;
  enemyShotPos = -2;

  int newCount = 0;
  for (int i=0; i<playerShotCount; i++) {
    int p = playerShots[i];
    // Odstraň pouze střely přesně na pozici výbuchu
    if (p == pos) continue;
    playerShots[newCount++] = p;
  }
  playerShotCount = newCount;

  addGameLogOnce("Výbuch na pozici " + String(pos) + ".");
}

void playExplosionFrame() {
  // Nepoužívat clearStrip() ani podbarvení celé scény, aby střely zůstaly viditelné
  // clearStrip();
  // for (int i = 0; i < LED_COUNT; i++) strip.setPixelColor(i, colorRGB(6,8,18));

  int fixedRadius = 3; // polovina délky exploze ~ 6 LED celkem
  int radius = (explosionFrame <= fixedRadius) ? explosionFrame : fixedRadius;

  for (int d = -radius; d <= radius; d++) {
    int p = explosionCenter + d;
    if (p < 0 || p >= LED_COUNT) continue;

    int intensity = 255 - (explosionFrame * 30);
    if (intensity < 40) intensity = 40;
    uint8_t r = min(255, intensity + 60);
    uint8_t g = max(0, intensity / 3);

    // Sloučení barvy výbuchu se současnou barvou LED pro efekt překrytí
    uint32_t currentColor = strip.getPixelColor(p);
    uint8_t cr = (currentColor >> 16) & 0xFF;
    uint8_t cg = (currentColor >> 8) & 0xFF;
    uint8_t cb = currentColor & 0xFF;

    uint8_t nr = min(255, cr + r);
    uint8_t ng = min(255, cg + g);
    uint8_t nb = cb; // výbuch žádnou modrou nepřidává

    strip.setPixelColor(p, colorRGB(nr, ng, nb));
  }

  strip.show();

  explosionFrame++;
  if (explosionFrame > EXPLOSION_FRAMES) {
    explosionActive = false;
    explosionCenter = -1;
    explosionFrame = 0;
    drawScene(); // Vykreslí scénu znovu bez exploze
  }
}



void enemyTryShoot() {
  if (gameOver) return;
  unsigned long now = millis();
  if (enemyShotPos == -1 && (now - lastEnemyShotTime >= ENEMY_SHOT_INTERVAL)) {
    enemyShotPos = LED_COUNT - 1;
    lastEnemyShotTime = now;
    addGameLogOnce("Nepřítel vystřelil (poz " + String(enemyShotPos) + ").");
  }
}

void updateShots() {
  if (gameOver) return;
  unsigned long now = millis();
  if (now - lastShotStep < SHOT_STEP) return;
  lastShotStep = now;

  // --- posun hráčových střel ---
  for (int i = 0; i < playerShotCount; i++) {
    playerShots[i]++;
  }

  // --- kontrola, zda hráčova střela nedošla do cíle ---
  int newCount = 0;
  for (int i = 0; i < playerShotCount; i++) {
    if (playerShots[i] >= LED_COUNT - 1) {
      gameOver = true;
      gameResult = "player_win";
      addGameLogOnce("Hráčova střela dosáhla cíle. Výhra hráče.");
      drawScene();
      return;
    }
  }

  // --- posun střely nepřítele ---
  if (enemyShotPos != -1) {
    enemyShotPos--;
    if (enemyShotPos <= 0) {
      gameOver = true;
      gameResult = "enemy_win";
      addGameLogOnce("Střela protivníka zasáhla hráče. Prohra hráče.");
      drawScene();
      return;
    }
  }

  // --- KOLIZE: hráčovy střely x střela nepřítele ---
  if (enemyShotPos != -1) {
    // Nové pole pro hráčovy střely, které nepřišly do kontaktu
    int updatedCount = 0;
    int explosionPos = -1;
    bool collisionDetected = false;

    for (int i = 0; i < playerShotCount; i++) {
      if (abs(playerShots[i] - enemyShotPos) <= 2) {
        // Kolize se střelou nepřítele
        collisionDetected = true;
        // Určíme pozici exploze jako střed první kolizní střely a nepřátelské
        if (explosionPos == -1) {
          explosionPos = (playerShots[i] + enemyShotPos) / 2;
        }
        // tuto střelu neukládáme do nového pole (tj. mažeme ji)
      } else {
        // střela není v kolizi, ponecháme ji
        playerShots[updatedCount++] = playerShots[i];
      }
    }

    // detekce kolize
    if (collisionDetected) {
      triggerExplosion(explosionPos);
      enemyShotPos = -1;
      playerShotCount = updatedCount;
    }
  }

  drawScene(); // vykresleni sceny
}




// Otazky z webu
void handleAnswer(uint8_t chosenIndex, String &responseJson) {
  if (gameOver) {
    responseJson = String("{\"status\":\"error\",\"message\":\"Hra skončila\",\"gameOver\":true}");
    return;
  }
  if (questions.size() == 0) {
    responseJson = String("{\"status\":\"error\",\"message\":\"Žádné otázky\"}");
    return;
  }

  turnCounter++;
  Question &q = questions[currentQuestionIndex];
  bool correct = (chosenIndex == q.correctIndex);
  String status = correct ? "correct" : "wrong";
  if (correct) {
    // vystřelí hráč, pokud je v poli místo
    if (playerShotCount < MAX_PLAYER_SHOTS) {
      playerShots[playerShotCount++] = 0; // new shot at LED 0
      addGameLogOnce("Hráč vystřelil protistřelu.");
    } else {
      addGameLogOnce("Hráč chtěl vystřelit, ale překročil maximální počet střel.");
    }
  } else {
    addGameLogOnce("Hráč odpověděl špatně.");

  }

  nextQuestionRandom();

  String json = "{";
  json += "\"status\":\"" + status + "\"";
  json += ",\"playerShotCount\":" + String(playerShotCount);
  json += ",\"enemyShotPos\":" + String(enemyShotPos);
  json += ",\"turnCounter\":" + String(turnCounter);
  json += ",\"gameOver\":";
  json += (gameOver ? "true" : "false");
  if (gameOver) json += ",\"result\":\"" + gameResult + "\"";
  json += "}";
  responseJson = json;
}

void handleSkip(String &responseJson) {
  if (gameOver) {
    responseJson = String("{\"status\":\"error\",\"message\":\"Hra skončila\"}");
    return;
  }
  if (skipsUsed >= 2) {
    responseJson = String("{\"status\":\"error\",\"message\":\"Maximální počet 'Ještě jednou' použit\"}");
    return;
  }
  skipsUsed++;
  nextQuestionRandom();
  addGameLogOnce("Ještě jednou použito.");
  drawScene();
  responseJson = String("{\"status\":\"ok\",\"skipsUsed\":") + String(skipsUsed) + String("}");
}

// Web server HTML generator
String generateIndexHtml() {
  String html = R"rawliteral(
<!doctype html>
<html lang="cs">
<head>
<meta charset="utf-8">
<meta name="viewport" content="width=device-width,initial-scale=1">
<title>hra Přežij!</title>
<style>
  :root {
    --bg: #0f1724;
    --card: #0b1220;
    --accent: #06b6d4;
    --muted: #94a3b8;
  }
  body {
    margin: 0;
    font-family: Inter, system-ui, Arial;
    background: linear-gradient(180deg, #041026 0%, #071733 100%);
    color: #e6eef6;
    padding: 20px;
  }
  .container {
    max-width: 1000px;
    margin: 0 auto;
  }
  .card {
    background: rgba(255, 255, 255, 0.02);
    border-radius: 10px;
    padding: 16px;
    margin-bottom: 14px;
  }
  h1 {
    margin: 0 0 8px 0;
  }
  .q {
    font-size: 18px;
    margin: 10px 0;
    color: #dbeafe;
  }
  .answers {
    display: flex;
    flex-direction: column;
    gap: 8px;
  }
  button.answer {
    width: 100%;
    padding: 12px;
    border-radius: 8px;
    border: 0;
    background: linear-gradient(180deg, var(--accent), #0b86a0);
    cursor: pointer;
    font-weight: 700;
  }
  .controls {
    display: flex;
    gap: 8px;
    align-items: center;
    margin-top: 10px;
  }
  .muted {
    color: var(--muted);
    font-size: 13px;
  }
  .led-preview {
    height: 28px;
    border-radius: 8px;
    background: linear-gradient(90deg, #00121e, #002233);
    display: flex;
    align-items: center;
    padding: 6px;
    overflow: hidden;
    width: 100%;
    box-sizing: border-box;
    margin-top: 8px;
  }
  .pill {
    height: 12px;
    border-radius: 6px;
    margin-right: 4px;
    flex: 0 0 auto;
  }
  .settings-container {
    display: flex;
    flex-direction: column;
    gap: 12px;
  }
  #gameResult {
    margin-bottom: 8px;
    font-weight: 700;
    font-size: 16px;
    color: #80ff80;
  }
</style>
</head>
<body>
<div class="container">
  <div class="card">
    <h1>hra Přežij!</h1>
    <div class="q" id="question">Načítám otázku…</div>
    <div id="answerMessage" style="color:#ff6666; font-weight:bold; margin-bottom:10px;"></div>
    <div class="answers" id="answers"></div>
    <div class="controls">
      <button id="skipBtn" class="answer">Ještě jednou (max 2x)</button>
      <button id="restartBtn" class="answer">Restart hry</button>
      <div style="margin-left:auto" class="muted">Kola: <span id="turnCounter">0</span></div>
    </div>
  </div>

  <div class="settings-container">
    <div class="card">
      <div class="small">Nahrát otázky (RAM only)</div>
      <textarea id="questionsText" rows="8" style="width:100%;background:transparent;color:inherit;border-radius:6px;padding:8px" placeholder="1; Kolik je 2+2?;3;4;5;6;2"></textarea>
      <div style="display:flex;gap:8px;margin-top:8px">
        <button id="uploadBtn" class="answer">Nahrát</button>
        <div id="uploadResult" class="muted"></div>
      </div>
    </div>

    <div class="card">
      <div class="small">Wi-Fi</div>
      <input id="ssid" type="text" placeholder="SSID" style="width:100%;padding:8px;border-radius:6px;background:transparent;color:inherit;margin-bottom:6px">
      <input id="pass" type="password" placeholder="Heslo" style="width:100%;padding:8px;border-radius:6px;background:transparent;color:inherit">
      <div style="display:flex;gap:8px;margin-top:8px">
        <button id="setWifi" class="answer">Uložit</button>
        <div id="wifiResult" class="muted"></div>
      </div>
    </div>
  </div>
</div>


<script>
let skipsLeft = 2;
let gameOverShown = false;

async function fetchState(){
  const res = await fetch('/state');
  if (!res.ok) return;
  const js = await res.json();
  document.getElementById('question').innerText = js.question || "Žádná otázka";
  const answers = js.answers || [];
  const answersDiv = document.getElementById('answers');
  answersDiv.innerHTML = '';
  for (let i=0; i<4; i++){
    const btn = document.createElement('button');
    btn.className = 'answer';
    btn.innerText = answers[i] || ('Odpověď '+(i+1));
    btn.onclick = () => submitAnswer(i+1);
    answersDiv.appendChild(btn);
  }

  document.getElementById('turnCounter').innerText = js.turnCounter || 0;
  skipsLeft = js.skipsLeft;
  document.getElementById('skipBtn').innerText = 'Ještě jednou (zbyvá ' + skipsLeft + ')';

  if (js.gameOver) {
    if (!gameOverShown) {
      const msg = (js.result === 'player_win') ? 'Vyhráli jste!' : 'Vyhrál protivník!';
      alert(msg);
      gameOverShown = true;
    }
  } else {
    gameOverShown = false;
  }

  // Render s předáním pole hráčových střel
  renderPreview(js.playerShotCount, js.enemyShotPos, js.explosionActive, js.fields, js.playerShotsPositions);
}


function renderPreview(playerShotCount, enemyShotPos, explosionActive, fields, playerShotsPos){
  const boxes = 40;
  const box = document.getElementById('ledPreview');
  box.innerHTML = '';
  for (let i=0;i<boxes;i++){
    const pill = document.createElement('div');
    pill.className = 'pill';
    pill.style.width = (100/boxes) + '%';
    pill.style.background = 'rgba(255,255,255,0.02)';
    pill.style.height = '12px';
    pill.style.marginRight = '3px';

    // Vykreslit nepřátelskou střelu
    if (enemyShotPos !== null && enemyShotPos !== undefined && enemyShotPos >= 0) {
      const mappedEnemy = Math.floor(enemyShotPos / (120/boxes));
      if (mappedEnemy === i) pill.style.background = 'linear-gradient(90deg,#ff8b8b,#ff3b3b)';
    }
    // Vykreslit hráčovy střely
    if (playerShotsPos && playerShotsPos.length > 0) {
      for (const pos of playerShotsPos) {
        if (pos !== null && pos !== undefined && pos >= 0) {
          const mappedPlayer = Math.floor(pos / (120/boxes));
          if (mappedPlayer === i) {
            pill.style.background = 'linear-gradient(90deg,#50ff70,#20a030)';
            break;
          }
        }
      }
    }
    // Exploze
    if (explosionActive) pill.style.background = 'linear-gradient(90deg,#ffb86b,#ff3b3b)';

    box.appendChild(pill);
  }
}

async function submitAnswer(idx){
  const res = await fetch('/answer', {method:'POST', headers:{'Content-Type':'application/x-www-form-urlencoded'}, body:'index='+idx});
  if (!res.ok) {
    const txt = await res.text();
    alert('Chyba: ' + txt);
    return;
  }
  const js = await res.json();
  
  const answerMsg = document.getElementById('answerMessage');
  
  if (js.status === 'correct') {
    answerMsg.style.color = '#70ff70';
    answerMsg.textContent = 'Odpověď ' + idx + ' - správně! (Vystřelena protistřela)';
  } else if (js.status === 'wrong') {
    answerMsg.style.color = '#ff6666';
    answerMsg.textContent = 'Odpověď ' + idx + ' - špatně! (Žádná protistřela)';
  } else {
    answerMsg.textContent = '';
  }

  await fetchState();
}

document.getElementById('skipBtn').addEventListener('click', async ()=>{
  if (skipsLeft <= 0) { alert('Už nemůžeš použít Ještě jednou.'); return; }
  const res = await fetch('/skip', {method:'POST'});
  const js = await res.json();
  if (js.status === 'ok') {
    document.getElementById('log').innerHTML = '<div>Ještě jednou použito</div>' + document.getElementById('log').innerHTML;
  }
  await fetchState();
});
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
void loop() {
  // wifi reconnect
  static unsigned long lastConnAttempt = 0;
  if (savedSSID.length() > 0 && WiFi.status() != WL_CONNECTED) {
    unsigned long now = millis();
    if (now - lastConnAttempt > 15000) { WiFi.begin(savedSSID.c_str(), savedPass.c_str()); lastConnAttempt = now; }
  }

  enemyTryShoot();
  updateShots();

  // kratká prodleva
  delay(2);
}

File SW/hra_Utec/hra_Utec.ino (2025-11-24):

/*
================================================================================
Uteč! - Hra pro ESPWLED s adresovatelným RGB LED páskem
================================================================================

Popis hry:
-----------
"Uteč!" je jednoduchá interaktivní hra, kde hráč závodí s duchem přes sérii polí
zobrazených adresovatelným LED páskem (např. WS2812B 60LED/m). Cílem hráče je dosáhnout
koncového pole dříve, než ho duch dohoní. Hráč postupuje správnými odpověďmi
na otázky, duch se pohybuje při chybných odpovědích, přičemž rychlost ducha se
zvyšuje s počtem kol.

Pravidla:
----------
1. Hráč začíná na předem definovaném poli (např. pole 3), duch na poli 1.
2. Hráč odpovídá na otázky zadané přes webové rozhraní.
3. Správná odpověď posouvá hráče o 1 pole vpřed.
4. Špatná odpověď posouvá ducha o 1–3 pole vpřed v závislosti na pořadí kola:
   - Kola 1–3: duch +1 pole
   - Kola 4–6: duch +2 pole
   - Kola 7+: duch +3 pole
5. Hráč může použít maximálně 2x možnost "Ještě jednou" pro přeskočení otázky
   bez postupu ducha.
6. Hra končí, když:
   - hráč dosáhne posledního pole → hráč vyhrává
   - duch dohoní nebo předběhne hráče → duch vyhrává
7. LED pás zobrazuje průběh hry:
   - Zelené LED: hráč
   - Červené LED: duch
   - Neaktivní pole: bílé LED na 10 % jasu
   - Při konci hry bliká LED pás podle vítěze

Použité knihovny:
------------------
1. Adafruit_NeoPixel  - pro ovládání adresovatelných LED.
2. AsyncTCP           - TCP server pro asynchronní komunikaci (základ pro ESPAsyncWebServer).
3. ESPAsyncWebServer  - asynchronní webový server pro webové rozhraní hry.
4. Preferences        - ukládání Wi-Fi přihlašovacích údajů a nastavení LED do NVS.
5. Vector (STL)       - uchování otázek v RAM.

Formát otázek:
--------------
Každá otázka se nahrává ve formátu CSV se 7 poli oddělenými středníkem:
ID;Otázka;Odpověď1;Odpověď2;Odpověď3;Odpověď4;IndexSprávnéOdpovědi(1..4)

- ID: unikátní číslo otázky (>0)
- Otázka: text otázky
- Odpovědi: 4 textové možnosti (musí být vyplněné)
- Index správné odpovědi: číslo 1–4, určující která odpověď je správná

Poznámky k implementaci:
------------------------
- Hra běží na ESPWLED (ESP32-C3), LED pásku (60LED/m, celkem 2m) je inicializován podle definovaného PINu a počtu LED.
- Webové rozhraní umožňuje:
  - Zobrazit aktuální otázku a odpovědi
  - Odeslat odpověď
  - Použít "Ještě jednou" (max 2x)
  - Restartovat hru
  - Nahrát nové otázky (RAM-only)
  - Nastavit Wi-Fi připojení, které se ukládá do NVS
- Otázky jsou uchovávány pouze v RAM, nejsou ukládány na SPIFFS.
- LED pás zobrazuje dynamicky hráče a ducha a indikaci konce hry.
================================================================================
*/

#include <WiFi.h>
#include <AsyncTCP.h>
#include <ESPAsyncWebServer.h>
#include <Adafruit_NeoPixel.h>
#include <Preferences.h>
#include <vector>

#define LED_PIN        5
#define LED_COUNT      120
#define LEDS_PER_FIELD 8
#define FIELDS         (LED_COUNT / LEDS_PER_FIELD) // 15

Adafruit_NeoPixel strip(LED_COUNT, LED_PIN, NEO_GRB + NEO_KHZ800);

AsyncWebServer server(80);
Preferences prefs;

// Game state
struct Question {
  String id;
  String text;
  String answers[4];
  uint8_t correctIndex; // 1..4
};

#define MAX_QUESTIONS 200
std::vector<Question> questions; // QUESTIONS IN RAM ONLY

int currentQuestionIndex = 0;
int playerField = 3; // starts on field 3
int ghostField = 1;  // starts on field 1
int turnCounter = 0; // increments after each answered question (correct or wrong)
int skipsUsed = 0;   // "Ještě jednou" used, max 2
bool gameOver = false;
String gameResult = ""; // "player_win" / "ghost_win" / ""

const char* apSsid = "hraUtecAP";
const char* apPass = "utec1234"; // nebo prázdné

// WiFi station creds stored in NVS (Preferences)
String savedSSID = "";
String savedPass = "";

// For reporting validation results
int lastValidCount = 0;
int lastInvalidCount = 0;

// Forward
void drawFields();
bool parseQuestionsFromString(const String &data);
String generateIndexHtml();
void nextQuestionRandom();
void resetGameState();

// ------- Utilities -------
void toLowerTrim(String &s) {
  // small helper
  s.trim();
}

// LED helpers
void setFieldColor(int field, uint32_t color) {
  if (field < 1) return;
  if (field > FIELDS) return;
  int start = (field - 1) * LEDS_PER_FIELD;
  for (int i = 0; i < LEDS_PER_FIELD; ++i) {
    strip.setPixelColor(start + i, color);
  }
}

void clearStripDim() {
  for (int i = 0; i < LED_COUNT; ++i) strip.setPixelColor(i, strip.Color(0,0,0));
}

void showStrip() {
  strip.show();
}

// map color helper
uint32_t colorRGB(uint8_t r, uint8_t g, uint8_t b) {
  return strip.Color(r,g,b);
}

// ----- Game logic -----
void resetGameState() {
  playerField = 3;
  ghostField = 1;
  turnCounter = 0;
  skipsUsed = 0;
  gameOver = false;
  gameResult = "";
  if (questions.size() > 0) currentQuestionIndex = 0;
  drawFields();
}

void checkEndConditions() {
  if (playerField >= FIELDS) {
    gameOver = true;
    gameResult = "player_win";
  } else if (ghostField >= playerField) {
    gameOver = true;
    gameResult = "ghost_win";
  }
}

void handleAnswer(uint8_t chosenIndex, String &responseJson) {
  if (gameOver) {
    responseJson = String("{\"status\":\"error\",\"message\":\"Hra skončila\",\"gameOver\":true}");
    return;
  }
  if (questions.size() == 0) {
    responseJson = String("{\"status\":\"error\",\"message\":\"Žádné otázky\"}");
    return;
  }
  turnCounter++; // one turn passed (answer submitted)
  Question &q = questions[currentQuestionIndex];
  bool correct = (chosenIndex == q.correctIndex);
  if (correct) {
    playerField += 1;
  } else {
    // ghost moves depending on turn count
    int ghostMove = 1;
    if (turnCounter <= 3) ghostMove = 1;
    else if (turnCounter <= 6) ghostMove = 2;
    else ghostMove = 3;
    ghostField += ghostMove;
  }
  checkEndConditions();
  // choose next question automatically (random)
  nextQuestionRandom();

  // update LEDs
  drawFields();

  // prepare response JSON
  String status = correct ? "correct" : "wrong";
  String json = "{";
  json += "\"status\":\"" + status + "\"";
  json += ",\"playerField\":" + String(playerField);
  json += ",\"ghostField\":" + String(ghostField);
  json += ",\"turnCounter\":" + String(turnCounter);
  json += ",\"gameOver\":";
  json += (gameOver ? "true" : "false");
  if (gameOver) json += ",\"result\":\"" + gameResult + "\"";
  json += "}";
  responseJson = json;
}

void handleSkip(String &responseJson) {
  if (gameOver) {
    responseJson = String("{\"status\":\"error\",\"message\":\"Hra skončila\"}");
    return;
  }
  if (skipsUsed >= 2) {
    responseJson = String("{\"status\":\"error\",\"message\":\"Maximální počet 'Ještě jednou' použit\"}");
    return;
  }
  skipsUsed++;
  nextQuestionRandom();
  // do not increment turnCounter, no ghost movement
  drawFields();
  responseJson = String("{\"status\":\"ok\",\"skipsUsed\":") + String(skipsUsed) + String("}");
}
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

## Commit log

2024-11-25 new data
    [ESPwled_v1_bom.csv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]
2025-11-28 Update hra_Prezij.ino
    color change, button settings
